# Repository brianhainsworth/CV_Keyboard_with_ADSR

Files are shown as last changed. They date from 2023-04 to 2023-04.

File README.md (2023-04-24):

# CV Keyboard with ADSR
A CV/GATE keyboard with ADSR for Eurorack or other modular synthesizers 

So I had been hanging out for a really simple little CV/GATE Keyboard for my modular setup. Like I've got a Beatstep, but having to get that out and separate power.... ugh. Instead I wanted something smack bang right in the rack, Easy peasy! I couldnt find anything that was in a Euro format so thats why I have put this together.

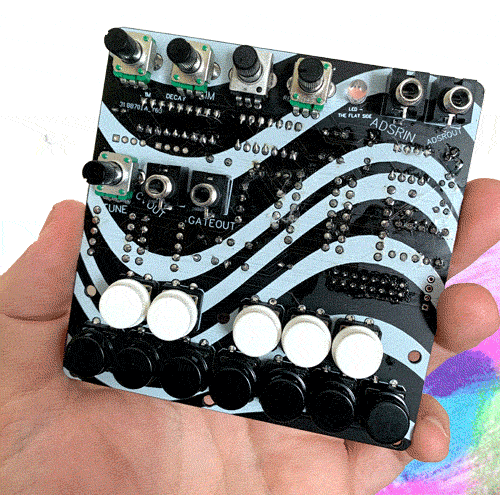
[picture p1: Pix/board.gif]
PCB


## The Design / Stealing from more talented people

Sure I think something could be done with arduino really easily, but the amount of times I've just been confused with the coding lead me to to [Ken Stones CGS-10](https://www.elby-designs.com/webtek/cgs/cgs10/cgs10_pedal.html). Ken Stone's design was for a matrix style keyboard which could be hooked up to an existing keyboard or buttons wired. His design is a little more than 1 octave, but because of size limitations and wanting it to look a bit pretty, I chopped off a couple notes. I have left the X and Y points for the matrix so if you wanted you could ignore the keyboard on the PCB and wire up your own buttons.

The keyboard uses a *Keyboard scanning chip, a 74C922* these seem to be a bit tricky to find these days, but I found one on [eBay.com](http://www.eBay.com), heck, they are probably knock-offs, fakes, whatever, but they do the trick. I wont link to them though as the listing will probably expire but just search geez. The 74C922 is the only kinda weird thing in this build, the rest came from [Tayda](https://www.taydaelectronics.com/) no worries.

I went for a 100mmx100mm PCB so I could get it in one of those cheapy deals from a PCB manufactuererer, it gives me enough space for the keyboard along the bottom without doing some weird horizontal thing. 
After putting the keyboard side of things together, I realised that there would be a bunch of space left over. I thought maybe a clock, but whatever a clock doesnt really relate to a keyboard, so I went with an ADSR.

The ADSR is taken from [Benjie Jiao's MiniADSR](https://benjiaomodular.com/post/2022-02-02-mini-adsr/) which in turn is taken from [René Schmitz' Fastest Envelope in the West.](https://www.schmitzbits.de/adsr.html) I like Benjie, he has always been kind, replies to me on insty and makes some cool stuff. 

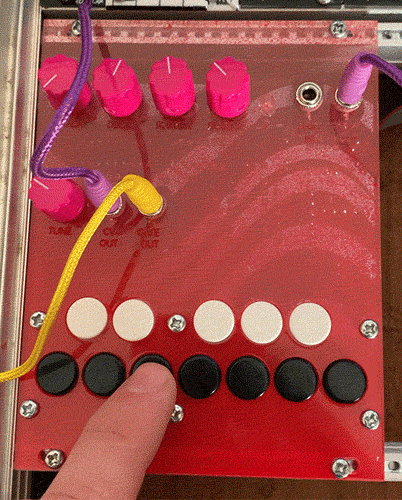
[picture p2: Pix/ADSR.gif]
ADSR in action


I slapped the ADSR together and hooked the gate out from the keyboard straight to the ADSR so that way if you dont have anything plugged into either of them the gate will trigger the ADSR so it all works together. BUT you can still use them independently from each other etc etc blah blah blah

Also the schematic here is a mess, I'm not going to tidy it up, sorry not sorry.

## Panel stuff

I make my panels out of 3mm acrylic / perspex. I get them laser cut at a local(ish) place which costs hardly anything. Your local library or makerspace could also do this for you. I suppose I do this as I reckon they would look terrible if I cut them myself out of aluminium or whatever. I suppose I could get them done at a metal fabricators. 

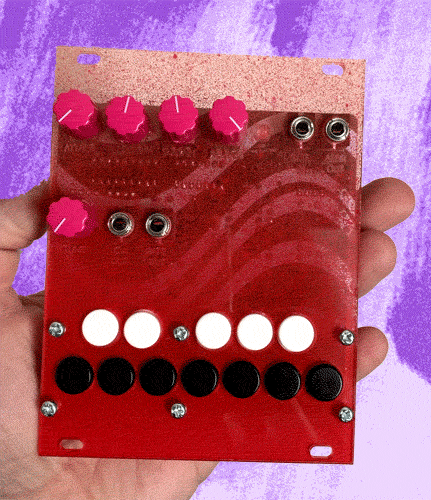
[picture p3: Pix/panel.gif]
Panel


ANYWAY 3mm acrylic is sturdy enough (2mm is not), I can paint it afterwards if I want and I can leave the LEDs under, not poking through. I think this will become more handy as Im starting to get brave enough to do some SMD stuff. I'm getting off track here...

With the 3mm acrylic there are a couple considerations...
- You gotta counter sink (not sure if that the right term) the PJ-3001f jacks. They have a little bit of a edge that makes things not sit flush. Use a stepped drill bit or you might shatter the acrylic.
- You gotta use the cheaper not threaded potentiometers. The height clearance of these means that the keyboard section will be too low on the panel, but maybe your into that, whatever. If I had picked different buttons you could probably use the threaded pots.

## Credits ###

CV/GATE keyboard design by Ken Stone - copyright 2001 by Ken Stone

MiniADSR design by BenjiaoModular - Copyright (c) 2022 Benjamin Joseph Jiao. Used under MIT License

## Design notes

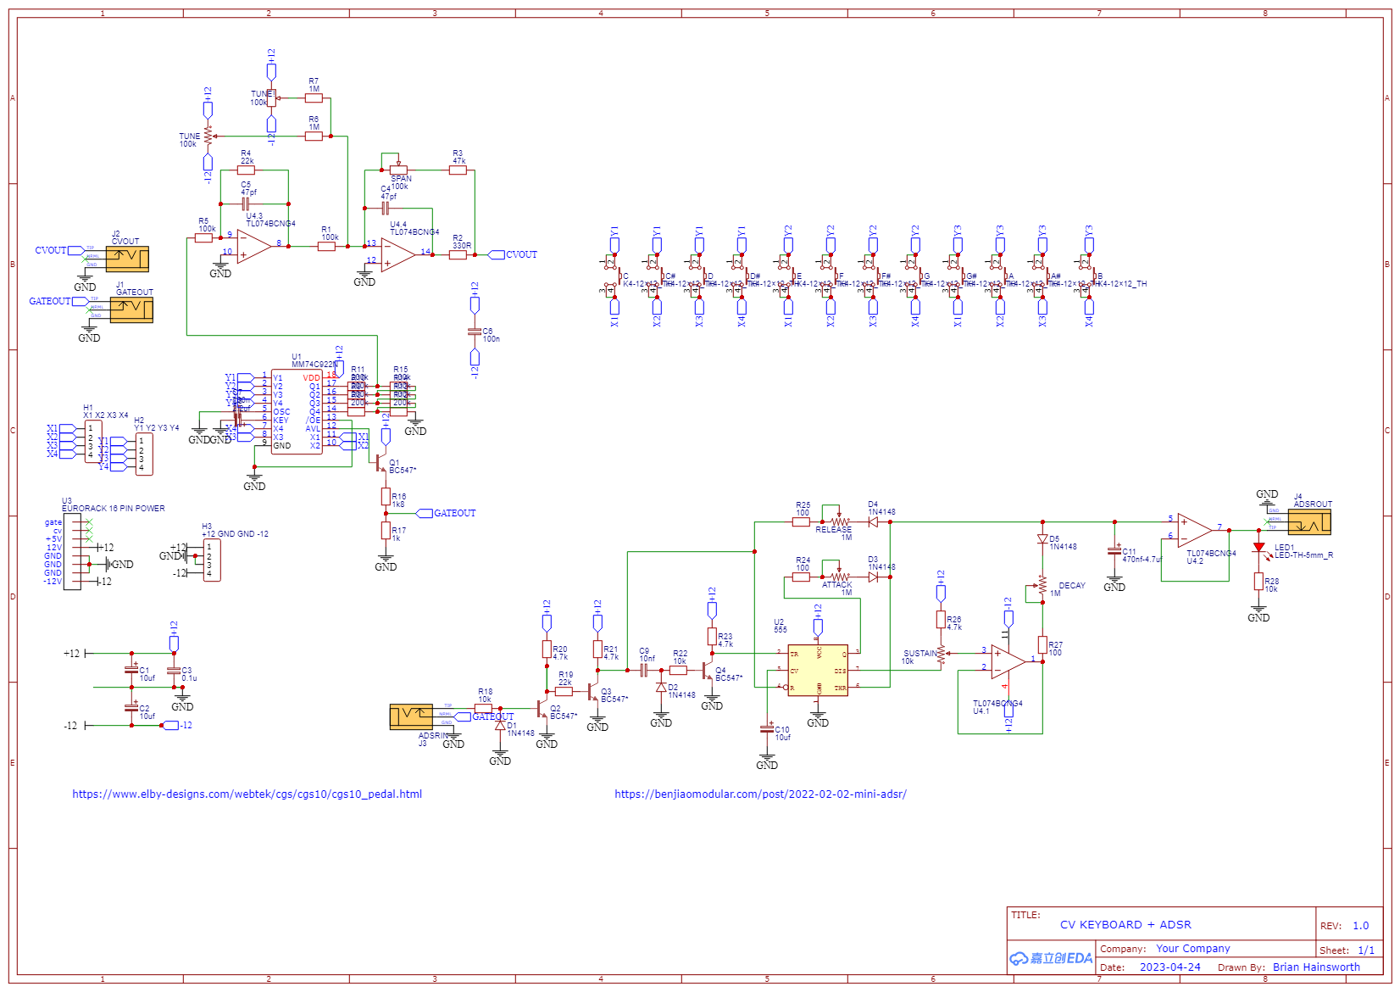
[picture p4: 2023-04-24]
Schematic_MiniCVGATE+ADSR.png

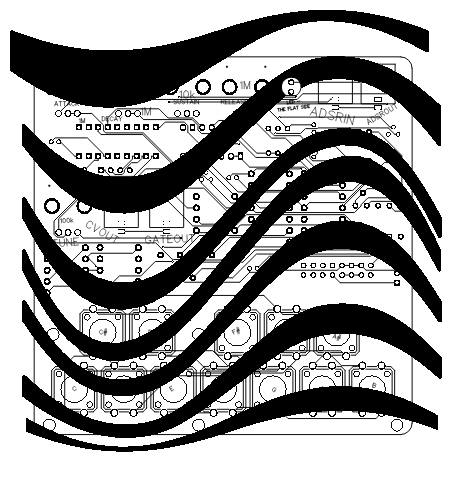
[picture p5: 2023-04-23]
PCB_PCB_MiniCVGATE-ADSR.png

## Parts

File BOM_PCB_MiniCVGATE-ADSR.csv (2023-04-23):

ID | Name | Designator | Footprint | Quantity | Manufacturer Part | Manufacturer | Supplier | Supplier Part | Price
1 | 100k | SPAN,TUNE! | RES-ADJ-TH_3296W | 2 |  |  | LCSC
2 | 10k | R18,R22,R28 | R_AXIAL-0.4 | 3
3 | BC547 | Q4,Q2,Q3,Q1 | TO92 | 4
4 | 0.1u | C3 | RAD-0.2 | 1
5 | 555 | U2 | DIP-8_W7.62MM | 1
6 | 1N4148 | D4,D3,D1,D5,D2 | DO-35_BD2.0-L4.2-P8.20-D0.5-RD | 5 | 1N4148 | STMicroelectronics | LCSC | C13769
7 | 22k | R4,R19 | R_AXIAL-0.4 | 2
8 | 47k | R3 | R_AXIAL-0.4 | 1
9 | 100 | R24,R27,R25 | R_AXIAL-0.4 | 3
10 | 10uf | C1,C2,C10 | CAP-D5.0×F2.0 | 3
11 | TL074BCNG4 | U4 | PDIP-14_L19.3-W6.4-P2.54-LS7.9-BL-1 | 1 | TL074BCNG4 | TI(德州仪器) | LCSC | C1348503 | 0.134
12 | MM74C922N | U1 | DIP-18 | 1 | MM74C922N
13 | 2.2uf | C8 | CAP-D5.0×F2.0 | 1
14 | 100k | R1,R5,R13,R14,R15 | R_AXIAL-0.4 | 5
15 | 10nf | C9 | RAD-0.2 | 1
16 | 1M | R6,R7 | R_AXIAL-0.4 | 2
17 | 1k8 | R16 | R_AXIAL-0.4 | 1
18 | 330R | R2 | R_AXIAL-0.4 | 1
19 | 470nf-4.7uf | C11 | CAP-D5.0×F2.0 | 1
20 | EURORACK 16 PIN POWER | U3 | EURORACK SHROUDED POWER 16 PIN | 1 | New SchematicLib
22 | 100n | C6,C7 | RAD-0.2 | 2
23 | 47pf | C5,C4 | RAD-0.2 | 2
24 | 200k | R12,R11,R9,R10,R8 | R_AXIAL-0.4 | 5
25 | 1k | R17 | R_AXIAL-0.4 | 1
26 | 4.7k | R23,R21,R20,R26 | R_AXIAL-0.4 | 4
27 | K4-12×12_TH | A,A#,B,C,C#,D,D#,E,F,F#,G,G# | KEY-TH_4P-L12.0-W12.0-P5.00-LS12.5 | 12 | K2-1103DP-M4SW-04 | 韩国韩荣 | LCSC | C128053 | 0.019
28 | 1M | ATTACK,DECAY,RELEASE | ALPHA9MMPOT-NOOUTLINE | 3 |  |  | LCSC
29 | 10k | SUSTAIN | ALPHA9MMPOT-NOOUTLINE | 1 |  |  | LCSC
30 | 100k | TUNE | ALPHA9MMPOT-NOOUTLINE | 1 |  |  | LCSC
31 | LED-TH-5mm_R | LED1 | LED-TH_BD5.0_RED | 1 | 333-2SURD/S530-A3 | EVERLIGHT(台湾亿光) | LCSC | C87271 | 0.007
32 | ADSRIN | J3 | PJ-3001F | 1 | PJ-3001F | Tayda Electronics | Tayda Electronics | PJ-3001F
33 | ADSROUT | J4 | PJ-3001F | 1 | PJ-3001F | Tayda Electronics | Tayda Electronics | PJ-3001F
36 | CVOUT | J2 | PJ-3001F | 1 | PJ-3001F | Tayda Electronics | Tayda Electronics | PJ-3001F
37 | GATEOUT | J1 | PJ-3001F | 1 | PJ-3001F | Tayda Electronics | Tayda Electronics | PJ-3001F

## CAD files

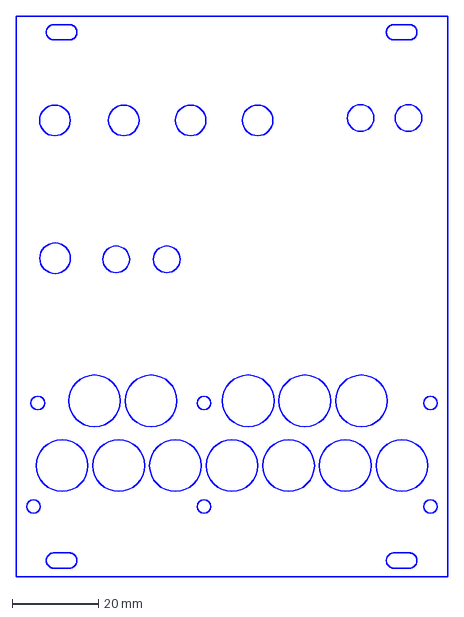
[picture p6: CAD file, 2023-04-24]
Panel-boardoutline for Laser Cutting-3mmAcrylic.dxf
100.0 x 130.0 mm

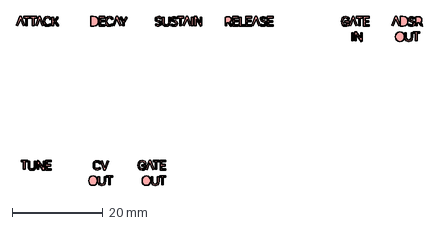
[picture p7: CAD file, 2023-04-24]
Paneltext for Laser Cutting-3mmAcrylic.dxf
89.7 x 37.4 mm

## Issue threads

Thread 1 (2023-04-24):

possible to get the CAD files for the CV keyboard?

KeLaiFu, 2023-04-24:
Thanks for making this euro module of the Ken stone original, I have had that on my to-do list forever and a day so I am SO happy to see you've done it already!
I was wondering if it was possible to share the kicad/eagle/whatever files you made for this? I'd like to play around with it.
The idea I was kicking around in my head when I saw the KS version was an 8hp IO module, with an additional keyboard module, either a second 8HP vertical style one, or a 1U horizontal one.
Totally understand if you want to keep those to yourself though, I will be glad to make your version either way.

brianhainsworth, 2023-04-24:
Heck, you are quick!! Its EasyEDA as I am new to all of this and I haven't figured anything else out yet. I'll try get something sorted for you in a bit

brianhainsworth, 2023-04-24:
I've uploaded the EasyEDA files. I haven't used these files, imported or exported to EasyEDA before, so use them at your own risk. I cant imagine them not working though. Maybe double check them to the schematic image or something

Closed 2023-04-24.

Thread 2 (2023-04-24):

appreaciated...but

KeLaiFu, 2023-04-24:
I've uploaded the EasyEDA files. I haven't used these files, imported or exported to EasyEDA before, so use them at your own risk. I cant imagine them not working though. Maybe double check them to the schematic image or something

_Originally posted by @brianhainsworth in https://github.com/brianhainsworth/CV_Keyboard_with_ADSR/issues/1#issuecomment-1519325113_

The EasyEDA file is much appreciated...but at the moment I dont think the scm.json can be imported into kicad which is my weapon of choice at the moment, however I believe the other file easyeda makes (I i think it's 'filename.easyeda.json') can be, is it possible to add that one?

Sorry to be a pain in the butt!

brianhainsworth, 2023-04-24:
No worries!

The only options I have to export out of EasyEDA is EasyEDA and Altium, Altium even gives some kind of weird warning as well so it might not work. I've exported the Altium files and added them if they are any use. My only other suggestion I can think of is to download EasyEDA, import them and then try exporting them to KiCAD yourself, that way you will know the settings and stuff that you need. I hope that helps, sorry if its not that helpful.

KeLaiFu, 2023-04-24:
I think it depends on which mode you are in at the time of export, although I am pretty clueless. The file you upped initially was the schematic file, which doesnt include the PCB layout information. In my brief playing with easyeda files in kicad, I was only able to import a board layout and play around with that, which is fine for something like this where I dont want to make any adjustments to the actual workings of the circuit. I'll take a look into it again later, now I have to work..gah!

KeLaiFu, 2023-04-24:
All good! Got the file into kicad, will try put my spin on things and all being well, I'll post the results on my github. Thanks again

Closed 2023-04-25.

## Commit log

2023-04-24 Add files via upload
    included EasyEDA files. I havent imported/exported project files like this before so use at your own risk. Gerbers are working tho.
2023-04-24 Add files via upload
    added dxf file for the panel, you should be able to import this to cad software if you wanted to make a panel out of a pcb or whatever
    [Panel for Laser Cutting-3mmAcrylic.dxf]
2023-04-24 Delete Panel for Laser Cutting-3mmAcrylic.dxf
    wrong file
    [Panel for Laser Cutting-3mmAcrylic.dxf]
2023-04-24 Add files via upload
    added dxf files for CAD if you want to make a panel out of PCB, separate files for board outline and top silkscreen
    [Panel-boardoutline for Laser Cutting-3mmAcrylic.dxf, Paneltext for Laser Cutting-3mmAcrylic.dxf]
2023-04-24 Add files via upload
    Gerbers for PCB panel. This is untested but should be all good. Based on original illustrator files
